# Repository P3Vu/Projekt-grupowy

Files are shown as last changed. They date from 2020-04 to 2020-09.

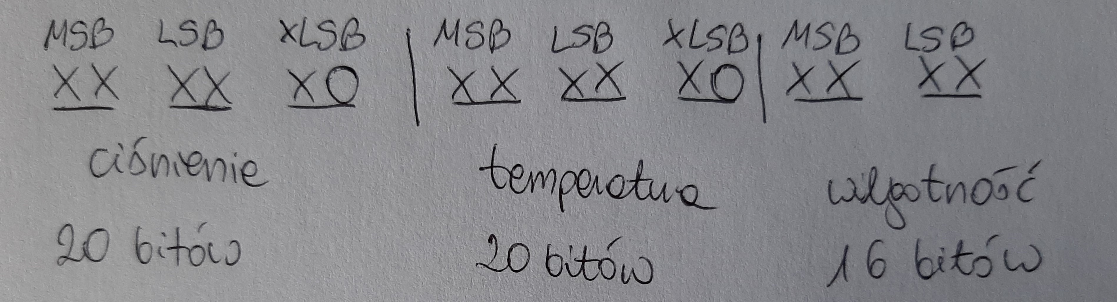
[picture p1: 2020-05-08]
Software/Czujnik BME280/dane.jpg

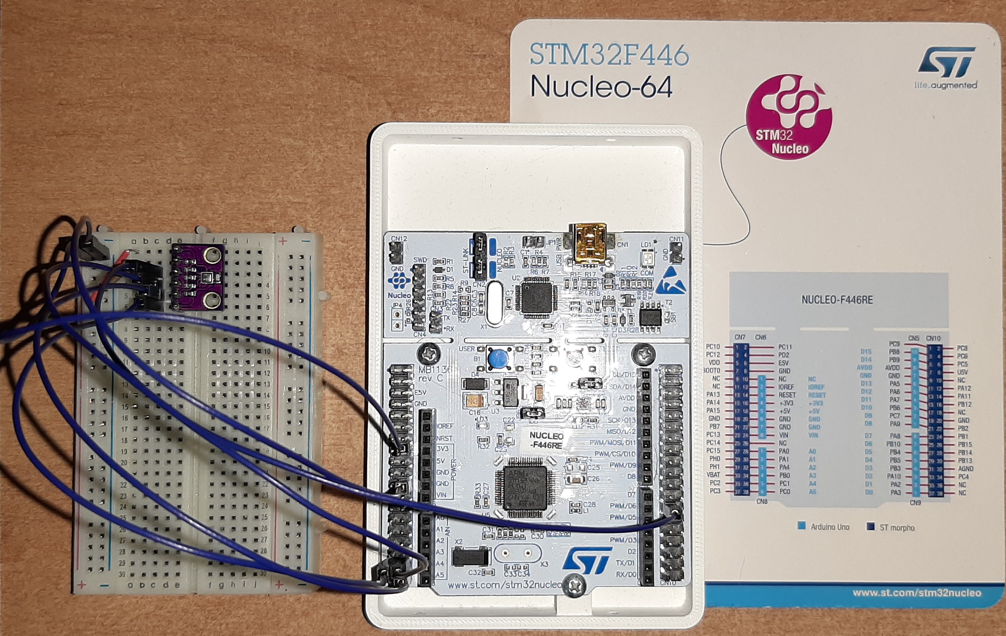
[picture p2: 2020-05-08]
Software/Czujnik BME280/podlaczenie.jpg

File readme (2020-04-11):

Repozytorium powstało na potrzeby projektu grupowego (Edycja 2020/2021) prowadzonego jako jedne z wymagań na II stopniu studiów 
kierunku Elektronika i Telekomunikacja.

Tematem projektu opisanego w repozytorium jest Rozproszony System Inteligentnego Oświetlenia Ulicznego, którego celem jest
stworzenie systemu składającego się z lamp ulicznych dokonujących odpowiednich pomiarów oraz komunikujących się bezprzewodowo
(np. z wykorzystaniem interfejsu LoRaWAN) z serwerem celem sterowania oraz zarządzania.

Członkami zespołu są studenci katedry Metrologii i Optoelektroniki z specjalizacją uzupełniająca Systemy Wbudowane:

1. inż. Paweł Wojciechowski (Lider Zespołu)
2. inż. Luiza Błaszczak
3. inż. Anita Kaszuba

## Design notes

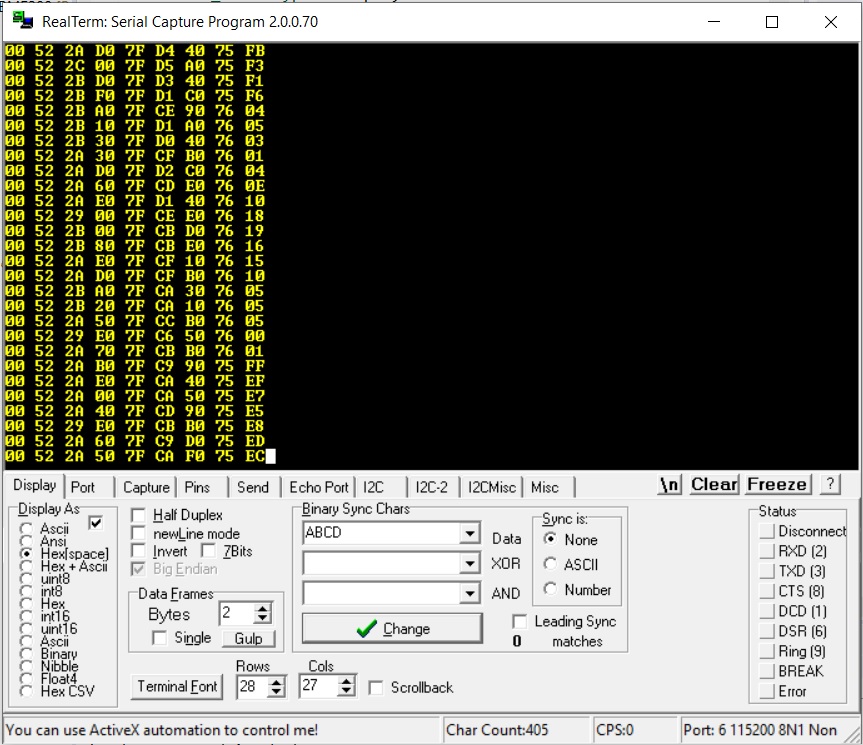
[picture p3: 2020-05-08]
Software/Czujnik BME280/terminal.jpg

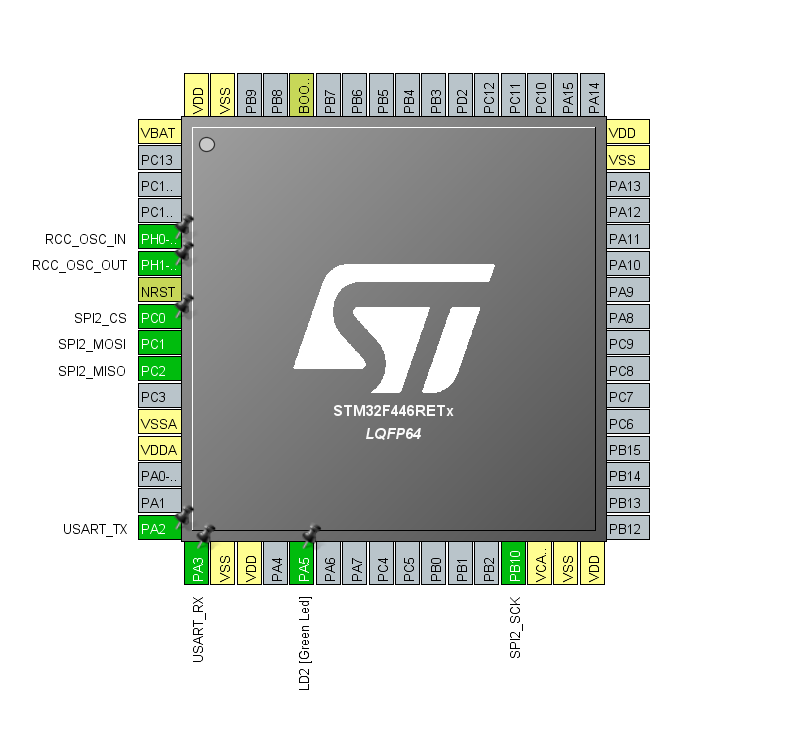
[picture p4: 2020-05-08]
Software/Czujnik BME280/cube.png

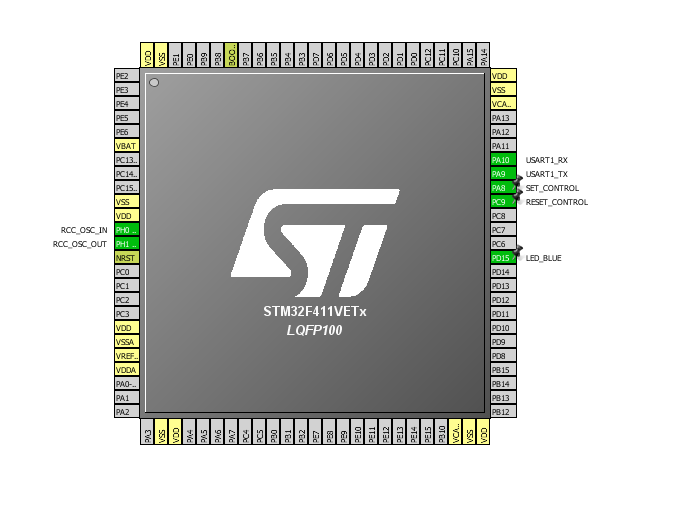
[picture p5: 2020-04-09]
Software/Czujnik PMS3003/procek.PNG

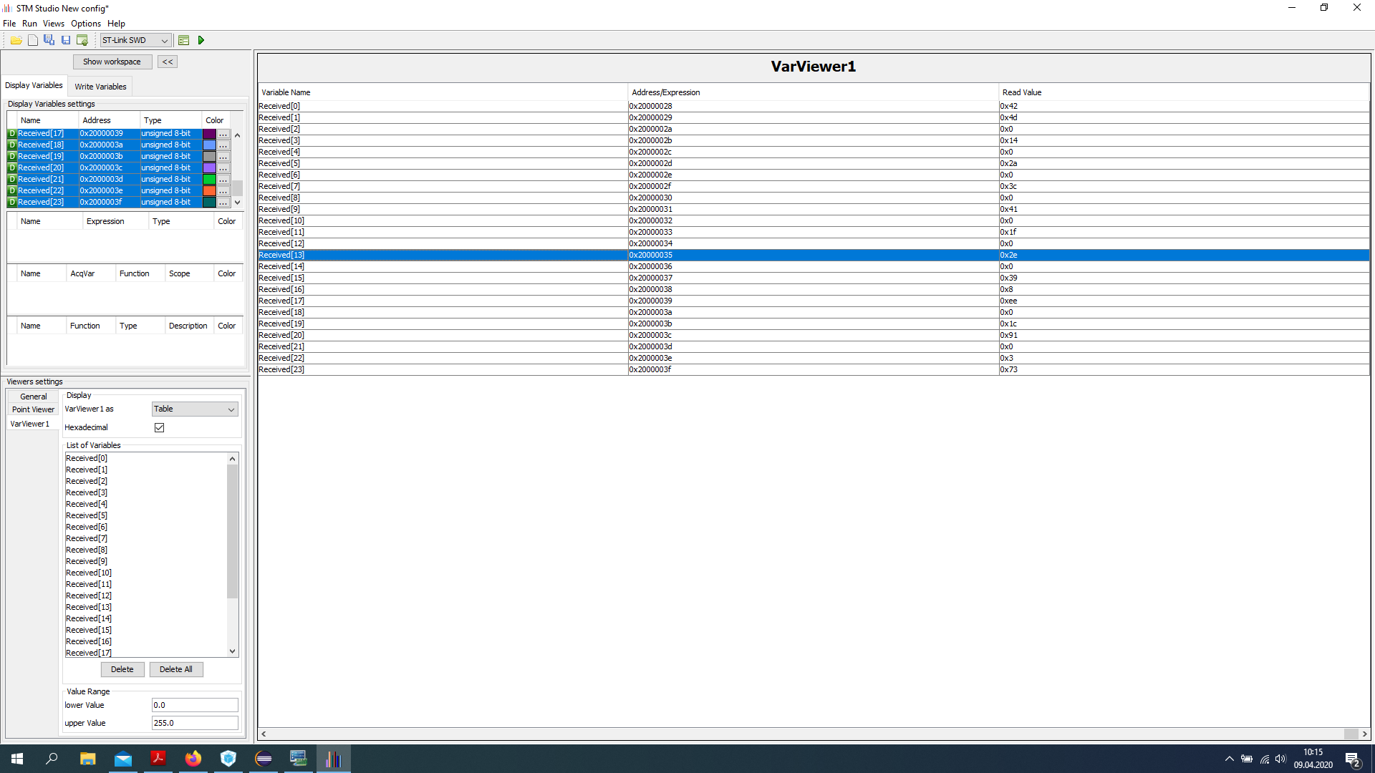
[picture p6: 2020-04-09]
Software/Czujnik PMS3003/screenshot z STM Studio.png

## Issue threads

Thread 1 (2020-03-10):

Literatura

P3Vu, 2020-03-10:
LoRaWAN :

- Część 1 omawia czym jest sama LoRa / LoRaWAN, część 2 bardziej praktyczna przedstawia o integracji z siecią TTN i bramkach
[](http://www.inzynierdomu.pl/lora-i-lorawan-czesc-2/)

-

Luiza2, 2020-03-11:
- przykładowe funkcje:
https://www.youtube.com/watch?v=YEg7jcKBTnk

P3Vu, 2020-03-18:
Pomiar napięcia przemiennego :
- dyskusja na elektrodzie
https://www.elektroda.pl/rtvforum/topic2819667.html

P3Vu, 2020-03-24:
_Transfer danych z TTN -> Serwer_
- https://www.thethingsnetwork.org/forum/t/extracting-data-from-ttn-to-my-server/6920/10

Luiza2, 2020-03-31:
- Detekcja zera sieci
[17] https://www.elektroda.pl/rtvforum/topic2791435.html
- Artykuł pomocniczy do odczytu sygnału
[18] http://mikrokontrolery.blogspot.com/2011/04/jak-mikrokontroler-widzi-sygnal-cyfrowy.html

P3Vu, 2020-04-12:
Czym jest ZigBee :

- Wstęp do ZigBee ( standard, budowa sieci - topologie i urządzenia w niej )
[19] https://przemysl-40.pl/index.php/2018/06/20/zigbee/

- Krótko ze strony STM-a ( schemacik SOC )
[20] https://www.st.com/en/applications/connectivity/zigbee.html

- Bardzo dokładnie o ZigBee
[21] https://pl.farnell.com/wireless-solutions-part-4-zigbee

P3Vu, 2020-04-30:
- Wybebeszona lampa :
https://www.youtube.com/watch?v=gyAi8HXgFR8

P3Vu, 2020-04-30:
Nowy procek od STM-a STM32WL ( LoRa )
Został ukazany w styczniu tego roku ale nie mogę go znaleźć nigdzie. Jedynie od ARROW-a w europie ale w paczce 50 sztuk. A tak to ani w postaci detalicznej procka ani już o devboardzie zapomnijcie.
Może do lipca bedzie dystrybucja to można zrobić na nim ( łączymy w 1 chipie procka STM i SX-a )

- Film od STM-a
[23] https://www.youtube.com/watch?v=Y3FifBLr4Pc

- Artykuł o nim
[24] https://elektronikab2b.pl/technika/51994-stm32wl-lora-i-mcu-w-jednym-chipie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

- Strona STM-a i dane o tym procku
[25] https://www.st.com/content/st_com/en/products/microcontrollers-microprocessors/stm32-32-bit-arm-cortex-mcus/stm32-wireless-mcus/stm32wl-series/stm32wlex/stm32wle5j8.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

P3Vu, 2020-05-03:
W kontekście diagnostyki pojedynczego węzła - pobór prądu. Przykładowy projekt licznika energii/gazomierza z odczytem przez neta :

- [26] https://www.elektroda.pl/rtvforum/topic3143998.html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

P3Vu, 2020-05-04:
Układ do rozłączania napięcia z baterii litowo-jonowej poniżej 3 V z pętlą histerezy wymagająca 3,09 V w celu ponownego włączenia układu.

- [27] https://www.analog.com/en/technical-articles/battery-protection-circuit.html#author

Luiza2, 2020-05-06:
Przykłady układów zasilających diody LED dużej mocy
- [28] https://ep.com.pl/files/2438.pdf

Luiza2, 2020-05-13:
Projektowanie PCB z wyprowadzeniem do podłączenia anteny
- [29] https://www.youtube.com/watch?v=14_jh3nLSsU

P3Vu, 2020-06-29:
Diody LED - jak realizować zasilanie

- [31] https://elektronikab2b.pl/technika/9988-diody-led-duzej-mocy.-jak-zrealizowac-zasilanie-poradnik-konstruktora

P3Vu, 2020-07-01:
Podłączenie diod mocy LED (porównanie 2 typów) - głównie zwrócić uwagę jak gościu je bada z źródłem prądowym.
- [32] https://www.youtube.com/watch?v=uDxDIflDYE0

Podstawy zasilania diod LED dużej mocy
- [33] https://www.youtube.com/watch?v=73KIi9C63hc

P3Vu, 2020-07-02:
Prosto o zasadach łączenia w szereg i równolegle diod mocy przy pomocy driverów
- https://www.youtube.com/watch?v=A1kz5d2dKDI

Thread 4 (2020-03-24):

Dostępne moduły komunikacji bezprzewodowej

P3Vu, 2020-03-24:
Hej, w tym wątku chciałbym opisywać po kolei możliwości jakie mamy na rynku. Dzięki temu będziemy mogli wspólnie wybrać najlepsze rozwiązanie dla naszego projektu. Skupie się tu głównie na omówieniu najważniejszych cech danego modułu, wsparcia po stronie społeczności czyli czy np. są biblioteki oraz w jakim języku najlepiej programujemy.

Podobną rzecz byłaby mile widziana po stronie **Anity** dla opisu możliwości integracji po stronie webowej / strony www. W ten sposób możemy dzielić się wiedzą. W tym wątku mile widziane jest wsparcie **Luizy** ;).

P3Vu, 2020-03-24:
1) STM32L0 - Discovery - LoRa B-L072Z-LRWAN1 ( wkrótce :) )

Luiza2, 2020-03-29:
Po przejściu SX1276 do trybu LoRa pojawia się możliwość wyboru trybu pracy modułu: "It is possible to access any mode from any other mode by changing the value in the RegOpMode register" (strona 36 dokumentacji). Rejestr RegOpMode został dokładnie opisany na stronie 108.

Znalazłam odpowiedź na nasze pytanie odnośnie komunikacji pomiędzy węzłami końcowymi: https://www.murata.com/en-global/support/faqs/products/lpwa/lora/hardware/0009
Niestety nie natknęłam się na przykład rozwiązania praktycznego ze względu na niekonwencjonalny sposób wykorzystania tej technologii (typowa jest topologia gwiazdy).

P3Vu, 2020-03-31:
d) Płytka The Things Uno czyli dev board od TTN na start z IoT - TME : 223 zł

Jest to dobra propozycja na start z prototypowaniem swojego IoT lub dla swojego projektu z komunikacją bezprzewodową z zasięgiem do 10 km. Jest oparta na Arduino Leonardo ( nie na Uno ) z dodatkowym modułem Microchip LoRaWAN. Jest w pełni kompatybilny z Arduino IDE i shieldami.

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

Źródło : https://www.thethingsnetwork.org/docs/devices/uno/

Interfejsy :
- GPIO
- PWM
- SPI
- UART

Rodzaj złącza :
- gniazdo Arduino
- ICSP
- USB B micro

Tak jak wyżej całość jest oparta na Leonardo + moduł LoRa. Myślę że warty uwagi jest ten moduł przy podejmowaniu decyzji przy budowie własnego PCB.

P3Vu, 2020-03-31:
e) Moduł ESP WiFi LoRa 32 - Cena do 100 zł przez aliexpress , 130 zł w Polsce.

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

Źródło : Wojciechowski p., Cyfrowa poziomica z interfejsem bezprzewodowym, Praca dypl., PG WETI 2019 ;)

Closed 2020-06-30.

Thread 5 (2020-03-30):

Raporty - Tydzień 1 30.03.20 - 5.04.20

P3Vu, 2020-03-30:
Wraz z początkiem kwietnia rozpoczynamy regularną pracę nad naszym projektem. Chciałbym wprowadzić cotygodniowe raporty, które pomogą nam utrzymać płynność pracy, zmobilizować się, ukierunkować zadania a także mnie jako liderowi dadzą większe poczucie komfortu panowania nad projektem. Póki co nie mamy możliwości spotykania się osobiście ( a szkoda ) ale fundamenty naszego projektu możemy zrealizować już teraz a gdy nadejdzie czas przejść wspólnie do praktycznej realizacji projektu.

W związku z powyższym chciałbym aby każdy z nas **do niedzieli godz. 20:00**  wstawił krótką notatkę z wykonanej pracy w mijającym tygodniu w tym wątku ( forma dowolna opis/podpunkty). Dzięki temu tego samego dnia jeszcze będę mógł się zapoznać z postępem pracy - udzielić pewne uwagi oraz zamknąć tydzień. Aktualizacja kolejnych tygodni będzie następować poprzez zmianę nazwy tematu wraz z nową datą.

W przypadku gdy wystąpi jakiś trudny tydzień dla danej osoby proszę po prostu napisać że nie było czasu - byle by był wpis. Pierwsze raport zgodnie z datą wstawiamy do 5 kwietnia.

P3Vu, 2020-04-04:
1. Wstawienie podstawowego opisu modułów : The Thigs Uno ( od TTN ) oraz ESP32 w kontekście godnych uwagi modułów do komunikacji LoRa
2. Zapoznanie się z dokumentacją czujnika PMS3003
3. Powrót do programowania dev board-a STM Discovery - kursik na forbot. Instalacja softu oraz pierwsze ćwiczenia z kursu.

Luiza2, 2020-04-05:
- ukończenie podstawowego kursu KiCad
- skonfigurowanie środowiska do programowania STM32 Nucleo i początek pracy nad biblioteką do czujnika BME280

anita-0, 2020-04-05:
- dogłębna analiza informacji o TTN na stronce producenta, sporządzenie listy zadań do zrobienia na TTN
- wstępny wybór sposobu integracji TTN żeby pobierać z niego dane - integracja http; mam nadzieję, że nic nie stanie na przeszkodzie i ten wybór nie będzie tylko wstępny :)

P3Vu, 2020-04-11:
- Implementacja oraz podlaczenie czujnika pylu PMS3003 do STM32
- Wstępne rozeznanie z ZigBee pod STM oraz zbieranie informacji na temat instalacji źródła oświetlenia ( w szczególności LED COB  )

Luiza2, 2020-04-11:
- nauka obsługi interfejsu SPI, komunikacja z modułem 74HC595
- analiza wymagań prawnych dotyczących oświetlenia ulicznego
- kompletowanie informacji o dostępnych czujnikach i sposobach wykrywania ruchu

anita-0, 2020-04-12:
- poznanie bardziej szczegółowych informacji na temat http, budowy aplikacji web
- rozpoczęcie kursu programowania aplikacji web
- skonfigurowanie i poznanie środowiska do java ee

P3Vu, 2020-04-19:
- Wspólnie opracowaliśmy Harmonogram naszego projektu
- W tym tygodniu jedynie luźno o ZigBee, zbieram informację na temat implementacji tego pomysłu w naszym projekcie ( na pewno pojawi się jakaś większa analiza w tym temacie )

anita-0, 2020-04-19:
Kurs aplikacji webowych in progress:
- tworzenie interfejsów, strony JSP
- serwlety, obsługa żądań

Luiza2, 2020-04-19:
- przegląd dostępnych metod wykrywania ruchu
- wstępne opracowanie systemu detekcji ruchu
- dogłębna analiza dokumentacji modułu BME280

anita-0, 2020-04-26:
- poznanie typowych znaczników JSTL - biblioteka znaczników rozszerzająca JSP
- komunikacja aplikacji webowych z bazą danych, wykorzystanie JPA - standard operowania na danych z bazy

P3Vu, 2020-04-26:
- Analiza przykładowej koncepcji pomiaru prądu wraz z odczytem przez internet

Luiza2, 2020-04-26:
- praca nad biblioteką do czujnika BME280

Luiza2, 2020-05-03:
- analiza komunikacji LoRaWAN (ograniczenia w komunikacji uplink i downlink)

P3Vu, 2020-05-03:
- Analiza i zakup modułów ZigBee, LoRaWAN oraz diod mocy LED do realizacji własnej mini-lampy we współpracy z Luizą

anita-0, 2020-05-03:
- przykłady użycia przydatnych funkcji i znaczników, manipulacja łańcuchami znaków

P3Vu, 2020-05-09:
- Wstęp do Power LED-ów, lamp LED, sterowania, przykładowymi metodami zasilania w oparciu o 'Elektronikę Praktyczną'
- Modernizacja Githuba
- Powrót do pracy z gitem w oparciu o kursy online
- Opracowanie pierwszy możliwości zasilania, zastosowania baterii oraz pomiaru prądu

Luiza2, 2020-05-10:
- praca nad biblioteką do czujnika BME280
- rozpoczęcie pracy z zestawem LRWAN-2
- pierwsze testy dwukierunkowej komunikacji bramka <-> TTN
- analiza modułów zasilania diod LED dużej mocy

anita-0, 2020-05-10:
- adnotacje , uwierzytelnianie
- formularze logowania i rejestracji

anita-0, 2020-05-17:
- zaplanowanie podziału aplikacji
- znalezienie platformy do uruchomienia aplikacji w sieci (AmazonAWS daje bezpłatny "hosting" na aplikację przez rok)
- wybór i instalacja środowiska do zarządzania bazami danych

P3Vu, 2020-05-17:
- Zgromadzenie oraz analiza dokumentacji i bibliotek do modułu ZigBee
- Pierwsze przetestowanie modułów w interfejsie BLE
- Próby podłączenia w interfejsie ZigBee

Luiza2, 2020-05-17:
- praca z dokumentacją modułów LoRaWAN

P3Vu, 2020-05-24:
- dalsza prace nad modułem ZigBee

anita-0, 2020-05-24:
- utworzenie projektu docelowej aplikacji, dodanie podstawowych wersji serwletów (które będą rozbudowywane)

Luiza2, 2020-05-24:
- uzupełnienie kodu czujnika o komentarze doxygen

P3Vu, 2020-07-05:
- Teoretyczne opracowanie pierwszej koncepcji zasilacza
- Przygotowanie listy zakupów pod prototyp zasilacza
- Koncepcja testowania

Luiza2, 2020-07-05:
- praca z mikrokontrolerem STM32WB (projekt zigbee)

anita-0, 2020-07-06:
- analiza rzeczy do zrobienia na najbliższy czas

P3Vu, 2020-07-11:
- Zakup, montaż oraz przetestowanie sterownika do oświetlenia

anita-0, 2020-07-12:
- Utworzenie bazy danych do przechowywania danych użytkowników
- Praca nad synchronizacją bazy i aplikacji

Luiza2, 2020-07-12:
- pisanie oprogramowania do integracji czujników wykrywających ruch z płytką Nucleo
- praca z projektem zigbee

Luiza2, 2020-07-19:
- integracja czujników z płytką Nucleo

P3Vu, 2020-07-19:
- Praca nad hardware-m drivera do LEDów

anita-0, 2020-07-19:
- próby synchronizacji bazy z aplikacją
- szczegóły o konfiguracji konta AWS (co dokładnie można, żeby było za darmo i jak to ustawić)

P3Vu, 2020-07-26:
- Praca nad hardwar-em drivera do LEDów (finish płytki, własne biblioteki, model 3D, BOM, przygotowanie do zamówienia elementów i pcb)
- Wycieczka do OBI po panel aluminiowy jako prototyp obudowy lampy

Luiza2, 2020-07-26:
- praca z projektem LoRaWAN

anita-0, 2020-07-26:
- założenie i skonfigurowanie konta w AWS
- wgranie aplikacji (niestety jeszcze coś nie działa)

P3Vu, 2020-08-02:
- Analiza i poprawki drivera oraz zamówienie PCB

anita-0, 2020-08-02:
- poprawki w ustawieniach aws i poprawne udostępnienie testowej aplikacji

anita-0, 2020-08-09:
- rozkminy nad bazą
- utworzenie konta na ttn

P3Vu, 2020-08-09:
Wstęp do firmware-u

Luiza2, 2020-08-09:
- utworzenie projektów do komunikacji za pomocą modułów CC2530
- integracja ZigBee i czujników

anita-0, 2020-08-16:
- Praca nad synchronizacją bazy, rozwikłany główny error

anita-0, 2020-08-30:
- ogarnięcie AWS, bo jakieś groszowe opłaty zaczęło naliczać
- próby z bazą wrrr

anita-0, 2020-09-13:
- jak tworzyć i zarządzać bazami bezposrednio przez aws
- informacje o integracji ttn z aws

P3Vu, 2020-09-13:
- Wstęp do programowania STM na rejestrach

anita-0, 2020-09-20:
- kurs AWS

Luiza2, 2020-09-20:
- uruchomione moduły zigbee
- dalsza walka z niedziałającym lorawanem

P3Vu, 2020-09-21:
- montaż lampy (pasta termoprzewodząca, ustawienie LEDek, pierwsze połączenia)

anita-0, 2020-09-27:
- udane łączenie aplikacji z bazą danych! (odczyt i zapis)

anita-0, 2020-10-04:
- testy komunikacji z bazą
- proste formularze logowania i rejestracji

P3Vu, 2020-10-04:
- zmontowanie lampy do końca
- wstępny research w sprawie pomiaru prądu wchodzącego do lampy (czego użyć, czujnik i-Snail wyglądał super ale nie ma go na rynku :( )

Luiza2, 2020-10-04:
- próby uruchomienia modułu LoRaWAN

P3Vu, 2020-10-12:
- Test całej lampy (wszystkie diodki ładnie świecą i wpierdzielają 1,4 Amp-a)
- Test a w zasadzie spalenie czujnika prądu :D, wpiąłem zgodnie z dokumentacją i poszedł z dymem za 3 cim podłączeniem ale już zamówiłem nowe scalaki więc czekanko

Luiza2, 2020-10-12:
- uruchomienie modułu LoRaWAN

P3Vu, 2020-10-16:
- Pomyślnie przeprowadzony test czujnika prądu na nowym scalaku
- Wyselekcjonowanie statywu do mocowania lampy
- Organizacja i raport z spotkania dla opiekuna projektu

anita-0, 2020-10-18:
- praca nad integracją z ttn
- projekt okna głównego apki
- podsumowanie dotychczasowych prac

P3Vu, 2020-10-25:
- Wywiercenie w lampie otworu montażowego pod statyw (trzeba jeszcze kupić prawdopodobnie nakrętkę motylkową M6)

anita-0, 2020-10-25:
- praca nad integracją z ttn

Luiza2, 2020-10-26:
- dodanie obsługi czujnika BME280 do węzła końcowego
- prace nad ramką danych przesyłaną do TTN

Luiza2, 2020-11-01:
- dodanie do projektu pomiaru wszystkich parametrów z czujnika BME280 i przesyłanie do TTN
- przetwarzanie danych z czujnika pyłów PMS3003
- dodanie wykrywania ruchu przez czujnik mikrofalowy

P3Vu, 2020-11-01:
- połączenie statywu z modelem lampy
- wstępne przemyślenia co do wykonania obudowy do lampy

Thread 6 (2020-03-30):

#1 Stacja oświetlenia ulicznego

P3Vu, 2020-03-30:
Pierwszym głównym elementem naszego projektu jest budowa prototypu tzw. stacji oświetlenia ulicznego. Poszczególne stacje będą dysponować specjalnie zaprojektowaną do tego zadania płytką integrująca wymagane komponenty - system wbudowany. Poniżej przedstawiam wspólny dla wszystkich części projektu schemat ideowy.

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

Bazując na dotychczasowych dyskusjach oraz analizując dostępne w sieci oraz tutaj na githubie pomysły dotyczące realizacji tej treści sporządziłem listę podpunktów jakie możemy zrealizować oraz pewne założenia :

- Wstępnie zakładamy architekturę gwiazdy Node <-> Gateway, ( opcjonalnie ) Architekturę liniową Node <-> Node <-> Gateway pozostawiamy na zdecydowanie dalszą część projektu

- Należy zapoznać się z możliwościami sterowania lampami LED, czego użyć do pierwszych testów - żarówką LED ? jak ewentualnie przenieść się na lamę uliczną, jak sama żarówka/lampa uliczna jest zbudowana oraz realizować regulację jasności. Dobór żarówki działającej pod 230V czy 12V ( te 2 mogą mieć lepsze wsparcie przy panelu solarnym - łatwiejsza integracja ).

_O sterowaniu domowymi LED-ami :_
http://www.fachowyelektryk.pl/technologie/oswietlenie/792-sterowanie-lampami-led.html

_O budowie zarówki LED :_
https://www.zarowka-led.com/blog/oswietlenie-led/budowa-zarowki-i-schemat-dzialania

- Czy myślimy o zainstalowaniu panelu solarnego ? Może wartoby było na poziomie systemu wbudowanego przewidzieć taką funkcjonalność - nie podejmować tego tematu od razu ale zrealizować na PCB okienko na to. Jak wykorzystać ? podłączyć ?

_Przykładowa lampa solarna, parametry oraz wstępne spojrzenie u producenta:_
https://www.brasit.pl/solarna-lampa-uliczna/

- Jakich czujników możemy używać do detekcji i co możemy wykrywać oraz w jaki sposób + przycisk awaryjny.

1. Czujnik wilgotności - rodzina DHT
2. Czujnik pyłu rodzina PMS do pomiarów PM10, 2.5, 1.0
3. Czujniki temperatury - wbudowany np. w STM czy zewnętrzny.
**4. Wykrywanie ruchu** - bardzo ważna kwestia tego projektu - jakie czujniki - jak mają reagować / wykrywać i jak to oprogramować.
5. Wykrywanie zmierzchu

- Jakie parametry możemy mierzyć i jak to robić ?

- Zasilanie - z sieci ? jak zintegrować je z modułem sterującym i jak dołączyć panel solarny - odnieść się do tego jak wygląda to w normalnej instalacji.

- Nawiązywanie komunikacji z bramką ( gateway ) - czy warto kupować swoją bramkę ?

- Przemyśleć ideę wieloczęściowego modułu sterującego tzn. czy warto rozdzielić go na moduł główny - moduł nadajnik/odbiornik - moduł oświetlenia ?

- Lampa LED ? Zbudujmy własną !
https://www.homemade-circuits.com/automatic-street-light-dimmer-using/

- ( opcjonalnie ) GPS
- ( opcjonalnie ) Lampa LED RGB

Artykuł na dobranoc :

_Lampy stosowane w oświetleniu ulicznym ze szczególnym uwzględnieniem źródeł LED_
https://edroga.pl/drogi-i-mosty/lampy-stosowane-w-oswietleniu-ulicznym-ze-szczegolnym-uwzglednieniem-zrodel-led-cz-i-07055814

Luiza2, 2020-03-31:
Wstępny opis zadań do wykonania.

Zadania teoretyczne:
- [ ] wybór źródła oświetlenia: LED 230V/12V/własne rozwiązanie
- [ ] pozostanie przy klasycznym oświetleniu czy RGB? - analiza wymagań prawnych
- [ ] decyzja o wykorzystaniu panelu słonecznego
- [ ] wybór modułu LoRaWAN
- [ ] opracowanie metody wykrywania ruchu:
              - czujnik ultradźwiękowy
              - czujnik mikrofalowy (z efektem Dopplera) https://botland.com.pl/pl/czujniki-ruchu/5497-dfrobot-gravity-czujnik-mikrofalowy-do-wykrywania-ruchu.html
- [ ] system detekcji zmierzchu
- [ ] propozycje czujników/modułów do wykorzystania:
              - czujnik BMP280 (pomiar temperatury, ciśnienia i wilgotności, w posiadaniu)
              - czujnik pyłów PM10, 2.5, 1.0
              - GPS NEO 6M  (w posiadaniu)

Część praktyczna:
- [ ] napisanie bibliotek do komunikacji z wybranymi modułami (wstępnie):
               - czujnik BMP280
               - czujnik pyłów
               - GPS?
- [ ] komunikacja wybranego modułu LoRaWAN z bramką i wstępne testy
- [ ] integracja systemu w postaci płytki PCB

P3Vu, 2020-04-09:
Zrealizowałem podłączenie czujnika PMS3003 do płytki Discovery STM32F411. Komunikacja z czujnikiem przebiega z wykorzystaniem interfejsu UART. Do tego czujnika **nie wymagane** jest napisanie odrębnej biblioteki programistycznej. Czujnik po podłączeniu do zasilania sam wysyła dane przez ten interfejs. Dokumentacja nie daje żadnych informacji co do możliwości komunikacji do czujnika ( ciekawe po co zatem linia RX po stronie czujnika ? może dla zachowania konwencji standardu UART albo programowania wbudowanego wewnątrz czujnika mikroprocesora ).

Pajączek z połączeniem :
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

Do obsługi czujnika wystarczy dane przychodzące po UARCIE wstawić do tablicy 24 bajtowej, gdyż tyle danych jest wysyłane z czujnika. Dane są wysyłane średnio raz na 1-2 sekundy ( szczegóły dokumentacja ). Żeby zidentyfikować czy dane przychodzą wykorzystałem dostępną na płytce diodę niebieska - kiedy ramka po UARCIE zostanie odebrana wywoływane jest przerwanie i przez callback ustawiam a właściwie zmieniam stan na diodzie na przeciwny. Oczywiście trzeba wystawić '1' na pinach SET i RESET które deklarujemy jako zwykłe GPIO_OUTPUT ( obie linie również zgodnie z dokumentacją podciągamy do 3V przez 10kOhm ). Bez tego czujnik nie rusza - sprawdzone :D . Wstawiłem do folderu 'Czujnik pylu' najważniejszą zawartość do eclips'a i cub'a oraz datasheet-a.

Przez STM Studio patrzymy na zawartośc odczytanych danych w tablicy Received :

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

I krótka analiza na papierze :

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

Jak widzimy dane w granicach 30-60 ug/m3 są realistyczne więc wszystko śmiga.

Luiza2, 2020-04-16:
**Wymagania i zalecenia w oświetleniu ulic.**

Dostęp do obowiązujących norm prawnych jest płatny. Sygnalizację dodatkowych zdarzeń można zrealizować w ramach eksperymentu.

Luiza2, 2020-04-16:
**Wstępna analiza metod wykrywania ruchu.**

Rodzaje czujników:
- **PIR (Passive Infra Red)** – działanie polega na wykrywaniu źródeł promieniowania podczerwonego,
- **mikrofalowy** – wykrywa ruch korzystając z efektu Dopplera. Ciągle emituje promieniowanie mikrofalowe i określa przesunięcie fazowe w mikrofalach odbitych w wyniku ruchu obiektu. Mikrofale przenikają przez cienkie materiały,
- **ultradźwiękowy**  – czujniki bardzo wrażliwe na ruch. Reagują na ruchy niewielkich obiektów. Nie pozwalają na odróżnienie ruchu obiektów żywych i przedmiotów, dlatego często łączy się je z czujnikami PIR,
- **laserowy** – czujniki wykorzystujące technikę ToF (Time of Flight)  - mierzy czas od wyemitowania impulsu z lasera podczerwonego do jego powrotu do detektora. Umożliwia wykonywanie dokładnych pomiarów. Rozwiązanie drogie w porównaniu z pozostałymi. Tańsze czujniki mają mały zasięg (największy zasięg jaki znalazłam to 4 m z rozdzielczością do 1 mm, granica do 50 zł),
- **dualny (pir + ultradźwiękowy)** – połączenie pozwala uniknąć błędnego wykrycia ruchu. Czujnik ultradźwiękowy zabezpiecza przed błędnym wykryciem obiektu wywołanym podmuchem ciepłego powietrza. Czujnik PIR zapewnia wykrywanie ruchu obiektów żywych. Operacja logiczna AND dwóch sygnałów daje lepsze efekty niż zastosowanie pojedynczej metody,

Dostępne czujniki
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
P3Vu, 2020-05-04:
**Zasilanie bateryjne w przypadku zaniku zasilania**

Tutaj chciałbym skorzystać z pojedynczej baterii Litowo-Jonowej (18650), która przy pojemności około 2000mAh pozwoliłaby na działanie naszego układu w stanie niskiego poboru mocy pozwalając na rozgłaszanie informacji o awarii głównego zasilania.

 **Moduł ładowania baterii**

Jedną z propozycji jest układ z rodziny TP4056/4054 pozwalający na ładowanie pojedynczej baterii Li-Ion prądem dochodzącym do 1A.

**Układ odcięcia przy zbyt niskim poziomie napięcia na bateriach**

Baterie Li-Ion są wrażliwe na zbyt niski poziom napięcia rozładowania. W tym celu należy zastosować układ który odłączy baterie w momencie gdy jej poziom napięcia będzie zbyt niski a konkretnie dla układu opisanego w [27] dla wartości 3V.

Wszystkie powyższe elementy oraz dodatkowo tranzystor przełączający napięcie główne jeżeli takie będzie dostępne od zapasowego oraz stabilizatorem LDO pod 3,3V stawią wstępną część zasilania.

P3Vu, 2020-05-04:
**Zasilanie**

Nasz układ jest zasilany w prost z sieci 230V AC stąd potrzebne jest przejście na niższe napięcie operacyjne. I jest tutaj kilka rzeczy do przemyślenia otóż potrzebne są nam zasadniczo 2 napięcia :

- 5 V które trafi do elementów bezpośrednio wymagających tego poziomu oraz przez tranzystor przełączający do LDO zbijającego napięcie do 3,3V.
- 12 V, które zasilać będzie diody mocy naszej lampy

Z tego powodu należy przemyśleć koncepcję zastosowania 1 trafo z oddzielnymi uzwojeniami ( 3,3V oraz 12V ), zastosowanie 2 odrębnych transformatorów ( trochę słabo :/ ) albo zmianę któryś z powyższych napięć przez odpowiednie układy.

P3Vu, 2020-05-04:
**Diagnostyka pojedynczej lampy pod kątem poboru prądu**

Elementem, który możemy wykorzystać do tego celu jest **Transduktor prądowy**. W naszym zastosowaniu pozwala on na generowanie sygnału 0-5V DC w zależności od sygnału przechodzącego przez pętlę magnetyczną na 230V AC. Przez dzielnik napięcia podajemy niskie napięcie na A/C w STM-ie. Ja natknąłem się na ten element przy okazji miernika energii elektrycznej [26].

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

Pozwala on na badanie obciążenia w zależności od wybranego układu w kombinacjach 10, 25, 50 oraz 100 A. Z informacji o pobieranym prądzie przez naszą lampę w stanie włączonym oraz wyłączonym jesteśmy w stanie przeliczyć ile energii zużywa zarówno lampa jak i LoRaBee, gdyż tak nazwałem płytkę komunikacji bezprzewodowej.

Luiza2, 2020-05-07:
**Czujnik wilgotności, ciśnienia i temperatury BME280**

**Informacje wstępne**

Zasilanie: 1.71-3.6V (wyprowadzenia Nucleo w stanie wysokim mają 3.3V :) )
Interfejs: I2C/SPI (3 bądź 4 przewodowy)
Zakres pracy:  -40... +85°C, 0 - 100% wilgotności, 300-1100hPa

Po doprowadzeniu zasilania czujnik pracuje w trybie **sleep mode**.

Dostępne tryby pracy:
- sleep mode: nie wykonuje operacji, wszystkie rejestry są dostępne, mniejszy pobr prądu,
- forced mode: wyzwala jeden pomiar, zapisuje wynik w rejestrach i powraca do sleep mode.
Tryb zalecany w zastosowaniach dopuszczających małe prędkości pomiarów,
- normal mode: ciągłe wyzawalanie pomiarów co czas zapisany w rejestrze 0xF5 config.

BME280 umożliwia wyłączenie np. czujnika temperatury, aby wykonywać dokładniejsze pomiary ciśnienia. Można ustawiać nadpróbkowanie wilgotności i zmieniać rozdzielczość pomiaru temperatury oraz ciśnienia. Urządzenie posiada filtr IIR który pozwala na uniknięcie przekłamań w pomiarach wywołany np. szybkim podmuchem wiatru.

Zalecane jest odczytywanie wielu rejestrów na raz a nie każdego pojedynczo. W trybie I2C nawet jeśli ciśnienie nie było mierzone to łatwiej odczytywać wszystko niż tylko  temperaturę i wilgotność.
Razem odczytuje się rejestry od 0xF7 do 0xFE (temperatura, ciśnienie i wilgotność).

20 bitów  dla ciśnienia i temperatury i 16 dla wilgotności.

W trybie normalnym czas pomiaru nie musi być zsynchronizowany z odczytem przez użytkownika.
Wyniki pomiarów mogą być dostępne gdy użytkownik dokonuje odczytu poprzedniego pomiaru.
W takim przypadku wykorzystuje się przepisywanie pomiarów do dodatkowych rejestrów w celu
zachowania spójności odczytów. Taki tryb jest dostępny tylko podczas jednoczesnego odczytania wszystkich rejestrów w jednej serii. Wykorzystanie kilku niezależnych odczytów może dać niespójne dane. Koniec odczytu serii jest sygnalizowany przez narastające zbocze CS w przypadku SPI lub ramki stop w przypadku I2C.

**Podłączenie do STM32Nucleo - F446RE**

Czujnik | Nucleo (SPI2)
:-------------------|:-------------------
SCL | PB10
SDA | PC1 (MOSI)
CSB| PC0
SDO| PC2  (MISO)

Wykorzystałam interfejs SPI. Prędkość transmisji wynosi 2,5 MBit/s (czujnik wymaga prędkości poniżej 10 MBit./s).

Realizacja układu:

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

Schemat:

Konfiguracja w STM32CubeMX:

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

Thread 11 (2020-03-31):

Plan projektu

Luiza2, 2020-03-31:
Wstępny opis zadań do wykonania.

- [ ] wybór źródła oświetlenia: LED 230V/24V/własne rozwiązanie
- [ ] wybór modułu LoRaWAN
- [ ] propozycje czujników/modułów do wykorzystania
                                        - [ ] czujnik BMP280 (pomiar temperatury, ciśnienia i wilgotności)
                                        - [ ] czujnik pyłów PM10, 2.5, 1.0
                                        - [ ] GPS NEO 6M
- [ ] opracowanie metody wykrywania ruchu
                                        - [ ] czujnik ultradźwiękowy
                                        - [ ] czujnik mikrofalowy (z efektem Dopplera)
- [ ] napisanie bibliotek do komunikacji z modułami
                                        - [ ]

Closed 2020-03-31.

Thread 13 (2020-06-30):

Projekt zasilacza do LEDów

P3Vu, 2020-06-30:
Wątek dotyczy problemu zaprojektowania podstawowego zasilacza do LEDów, który umożliwiłby ich sprawne działanie w konfiguracji 1 lub wielu gałęzi a dodatkowo :

- Umożliwiałby ściemnianie (najprawdopodobniej przez PWM) wszystkich LED
- Przyjmowałby na wejście napięcie z sieci 230V AC i przez transformator wejściowy (1 lub 2 stopniowy dla napięcia 12/5/3,3V) zbijałby napięcie dla poprawnej pracy scalonego stabilizatora obniżającego (raczej nie chcemy podwyższającego lub obnż-podwyż)

Dodatkowe rzeczy na które warto zwrócić uwagę lub które mogą się pojawić przy okazji tego zagadnienia to wykorzystanie tranzystora mocy MOS, układy pętli sprzężenia zwrotnego, zabezpieczenia termiczne, prądowe, przepięciowe.

Firma która zajmuje się projektowaniem scalaków do takich rzeczy to np. **Power Integrations**.
Dodatkowe informacje w literaturze [31].

Pierwszy schemat :
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

P3Vu, 2020-07-05:
Pierwsza podejście do projektu zasilacza rozpoczynam od przeanalizowania informacji ogólnych zaproponowanych poniżej :

https://ea.elportal.pl/zasilacze.html

Dowiadujemy się stąd podstawowych informacji za pomocą których możemy zrealizować podstawowy zasilacz oraz jakie elementy dobrać. W oparciu o to zrealizowałem schemat blokowy z wstępnie zdefiniowanymi elementami. Pod schematem blokowym zamieszczam dodatkowe obliczenia oraz informacje jakie mogą się przydać przy następnych rewizjach.

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

**Power LED**

Pierwszy błąd jaki popełniliśmy przy okazji samego projektu to zbyt wczesna decyzja o zakupie power LEDów. Nie sprawdziłem dokładnie informacji o sposobie ich zasilania i tu wyszedł pierwszy problem otóż wymagają one ograniczenia prądowego.

Diody które my wybraliśmy to 'High Power LED - 1W WLW28-140' są białymi power LED-ami a ich najważniejsze parametry to:

- moc możliwa do rozproszenia: 1,2 W
- maksymalny szczytowy prąd w impulsie: 0,5 A
- prąd ciągły: 0,35 A
- napięcie wsteczne: 5 V
- napięcie progowe: 3 ~ 3,6 V przy 350 mA

Do ledów mamy dołączone radiatory 1Watowe, który umożliwią rozproszenie części i całe szczęście bo bez nich same diody nie poradziłyby sobie 3,6*0,35 = 1,25 W. Prawidłowo takie ledy montuje się na 'belkach' w postaci blachy miedzianej i łączy się szeregowo/równolegle w zależności od możliwości zasilania. Do belki 'przyklejamy nasze ledy przy pomocy pasty termo-przewodzącej (nie wiem czy sama pasta zapewnia przyklejenie ale zapewnia termo-połączenie).

**Driver**

Skoro mamy już diody te jakie mamy, starałem się dopasować to sytuacji i wyselekcjonować odpowiednie zasilanie. Generalnie uważam że diody są nawet ok jak na start więc nie był to zły wybór ale błędne było samo podejście.

 Skoro diody wymagają od nas źródła prądowego 350 mA, dodatkowo chcielibyśmy nimi jakoś sterować to potrzebny jest nam sterownik, który nam to zapewni. I tutaj mamy różne możliwości ale jeżeli trafił się już jakiś godny uwagi to trudno dostępny na naszym rynku, stąd zrobił podejście w drugą stronę - patrzałem co mamy na rynku a z tego co jest wybrałem sterownik.

Zatrzymałem się na **STCS1**

**Stabilizator**

**Prostowanie i filtr**

**Transformator**

**Wnioski**

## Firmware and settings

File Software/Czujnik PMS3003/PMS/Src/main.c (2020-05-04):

/**
  ******************************************************************************
  * @file           : main.c
  * @brief          : Main program body
  ******************************************************************************
  ** This notice applies to any and all portions of this file
  * that are not between comment pairs USER CODE BEGIN and
  * USER CODE END. Other portions of this file, whether 
  * inserted by the user or by software development tools
  * are owned by their respective copyright owners.
  *
  * COPYRIGHT(c) 2020 STMicroelectronics
  *
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
  ******************************************************************************
  */
/* Includes ------------------------------------------------------------------*/
#include "main.h"
#include "stm32f4xx_hal.h"

UART_HandleTypeDef huart1;

/* USER CODE BEGIN PV */

uint8_t Received[24];

/* USER CODE END PV */

void SystemClock_Config(void);
static void MX_GPIO_Init(void);
static void MX_USART1_UART_Init(void);

/* USER CODE BEGIN PFP */

void HAL_UART_RxCpltCallback(UART_HandleTypeDef *huart){

	HAL_UART_Receive_IT(&huart1, Received, 24);
	HAL_GPIO_TogglePin(LED_BLUE_GPIO_Port, LED_BLUE_Pin);

}

/* USER CODE END PFP */

/**
  * @brief  The application entry point.
  *
  * @retval None
  */
int main(void)
{
  /* MCU Configuration----------------------------------------------------------*/

  /* Reset of all peripherals, Initializes the Flash interface and the Systick. */
  HAL_Init();

  /* Configure the system clock */
  SystemClock_Config();

  /* Initialize all configured peripherals */
  MX_GPIO_Init();
  MX_USART1_UART_Init();
  /* USER CODE BEGIN 2 */

  HAL_GPIO_WritePin(SET_CONTROL_GPIO_Port, SET_CONTROL_Pin, GPIO_PIN_SET);
  HAL_GPIO_WritePin(RESET_CONTROL_GPIO_Port, RESET_CONTROL_Pin, GPIO_PIN_SET);

  HAL_UART_Receive_IT(&huart1, Received, 24);

  /* USER CODE END 2 */

  /* Infinite loop */
  /* USER CODE BEGIN WHILE */
  while (1)
  {

  /* USER CODE END WHILE */

  /* USER CODE BEGIN 3 */

  }
  /* USER CODE END 3 */

}

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


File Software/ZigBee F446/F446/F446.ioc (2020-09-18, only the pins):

Mcu.UserName=STM32F446RETx
PA0-WKUP.Signal=UART4_TX
PA1.Signal=UART4_RX
PA10.Signal=USART1_RX
PA13.GPIO_Label=TMS
PA13.Signal=SYS_JTMS-SWDIO
PA14.GPIO_Label=TCK
PA14.Signal=SYS_JTCK-SWCLK
PA2.GPIO_Label=USART_TX
PA2.Signal=USART2_TX
PA3.GPIO_Label=USART_RX
PA3.Signal=USART2_RX
PA5.GPIO_Label=LD2 [Green Led]
PA5.Signal=GPIO_Output
PA9.Signal=USART1_TX
PB10.Signal=USART3_TX
PB13.Signal=GPIO_Output
PB3.GPIO_Label=SWO
PB3.Signal=SYS_JTDO-SWO
PC12.Signal=UART5_TX
PC13.GPIO_Label=B1 [Blue PushButton]
PC13.Signal=GPXTI13
PC14-OSC32_IN.Signal=RCC_OSC32_IN
PC15-OSC32_OUT.Signal=RCC_OSC32_OUT
PC3.Signal=GPXTI3
PC4.Signal=GPIO_Output
PC5.Signal=USART3_RX
PD2.Signal=UART5_RX
PH0-OSC_IN.Signal=RCC_OSC_IN
PH1-OSC_OUT.Signal=RCC_OSC_OUT

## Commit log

2020-05-04 Projekt PCB
    [LoRaBee.kicad_pcb, LoRaBee.sch]
2020-05-08 Added Czujnik BME280
    [BME280 Run.cfg]
2020-05-08 Modernizacja repozytorium
    [BME280 Run.cfg]
2020-07-03 Zalozenie projektu w Eagle oraz dodanie schematu blokowego
    [LoRaBee.kicad_pcb, LoRaBee.sch, PowerLED.sch]
2020-07-03 Poprawienie schematu blokowego
    [PowerLED.sch]
2020-07-04 Kosmetyczne poprawki
    [PowerLED.sch]
2020-08-09 Komunikacja za pomoca CC2530
    [F446 Run.cfg, L073 Run.cfg]

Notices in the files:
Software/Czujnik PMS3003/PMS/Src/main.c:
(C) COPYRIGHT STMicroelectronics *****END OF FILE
